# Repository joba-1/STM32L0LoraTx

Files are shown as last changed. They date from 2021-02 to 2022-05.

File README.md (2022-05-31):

# STM32L0LoraTx

Firmware and PCB for a device that sends data with a STM32L0/RFM95, battery or solar powered, to a [LoraGW ESP8266/RFM95 node](https://github.com/joba-1/LoraGw)

## Build

* Download and install STM32CubeIDE (as of now version 1.5.1)
* Import this repo
* Open .ioc file and select "Project/Generate Code" (should download needed "firmware" files for the chip from ST)
* Build Release or Debug

## Wiring

connect Gnd of all components

### STM32L011

Not checked without, but generally recommended to use a small ceramic (~10nF) and big electrolyt condensator (~10µF) between + and - near STM pins

* Look at the ioc file with CubeMX pinout view.
* Vdd _and_ Vdda to 1.8-3.3V
* Vss to Gnd
* Boot0 pulled to Gnd (~10k) to safely boot from flash
* STLink for flashing and debug: SWD, SWC, Gnd, NRst (also can provide Vdd via JP1 and STLink-Rx to L0-Tx for serial out)

### BME280

* SDA=MOSI, SDC=MISO, others should be obvious

### RFM95W

* Ant=~8cm wire (vary length and position to get best average RSSI as reported by LoraRx). 
* NSS=CS, others should be obvious

### Serial

Rx of a usb to serial converter sends at 115200. I use this command (serial port name ttyUSB_ser_red is defined in my /etc/udev/rules.d)
    pio device monitor -p /dev/ttyUSB_ser_red -b 115200

### LED

can be used without resistor. I use 1kOhm to save battery

## References

Good resource for STM32 is [Stefan Frings](http://stefanfrings.de/stm32/stm32l0.html)
He has links to reference, datasheet, errata and more. E.g.:

* [STM32L011 Datasheet](https://www.st.com/resource/en/datasheet/stm32l011d3.pdf)
* [STM32L011 Reference](https://www.st.com/resource/en/reference_manual/dm00108282-ultra-low-power-stm32l0x1-advanced-arm-based-32-bit-mcus-stmicroelectronics.pdf)
* [STM32L011 Errata](https://www.st.com/resource/en/errata_sheet/dm00237371-stm32l011x3-4-device-limitations-stmicroelectronics.pdf)
* [Power consumption](http://www.st.com/content/ccc/resource/technical/document/application_note/27/58/8e/81/79/fb/4f/ac/DM00108286.pdf/files/DM00108286.pdf/jcr:content/translations/en.DM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)

## Power Info Bits

* Examples for LL are here: STM32Cube/Repository/STM32Cube_FW_L0_V1.11.2/Projects/NUCLEO-L073RZ/Examples_LL/RTC/RTC_ExitStandbyWithWakeUpTimer
* Periodic wakeup timer is in Reference 22.4.6 (Periodic auto-wakeup)
* 1s to 18h periodic wakeup with ck_spre = 1s (see 22.4.3) and WUCKSEL [2:1] = 10
* Enable by WUTE bit in RTC_CR register
* Once setup it runs in normal and low power. 
* Sets WUTF flag in RTC_ISR if elapsed and reloads RTC_WUTR (timer counter). User resets WUTF
* Set WUTIE bit in RTC_CR to generate interrupt to wake up from low power modes
* System reset and Sleep, Stop, Standby have no influence on the WUT (wakeup timer)
* Save Lora frame counter in backup register: Reference 22.7.20 RTC backup registers (RTC_BKPxR)
* I couldnt make it work with LL lib, had to use big fat HAL for RCC and RTC. What is missing?

        LL_RTC_DisableWriteProtection(RTC);
        LL_RTC_WAKEUP_Disable(RTC);
        while( !LL_RTC_IsActiveFlag_WUTW(RTC) );
        LL_RTC_WAKEUP_SetClock(RTC, LL_RTC_WAKEUPCLOCK_CKSPRE);
        LL_RTC_WAKEUP_SetAutoReload(RTC, 3); // wake up every 3+1 s
        LL_RTC_EnableIT_WUT(RTC);
        LL_RTC_WAKEUP_Enable(RTC);
        LL_RTC_EnableWriteProtection(RTC);
        while( LL_RTC_IsActiveFlag_WUTW(RTC) );
        LL_RTC_ClearFlag_WUT(RTC);
        NVIC_ClearPendingIRQ(RTC_IRQn);

## Status

Working and sending LoRa packets to my LoraGW ESP8266 gateway (battery voltages and bme280 weather data)

Two devices operating with 2 AA 1.5V batteries (so far using 0.2-0.4 V per year, so >5 years between battery swaps is more than realistic).
They send battery voltage data from within a car trunc - not ideal for RF :) - to a nearby house with no signal problems.

One device runs "forever" with a 3.7 Lipo ~1.6Ah, a ~3x8 cm² 5V solar cell and a small solar charger board (reducing vcc out a bit with a diode). No capacity problems during winter.

## Todo

* Provide more sensor data (probably more ADC stuff and more generic)
* Move GPIO pins (CS, LED) to non-ADC pins to have them available for voltage measurements

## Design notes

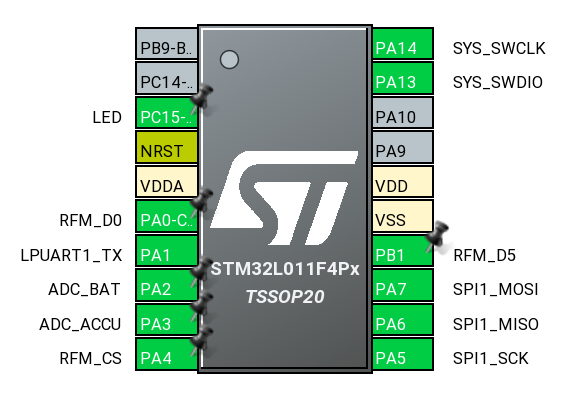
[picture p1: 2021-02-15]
STM32L011-TSSOP20-pinout.png

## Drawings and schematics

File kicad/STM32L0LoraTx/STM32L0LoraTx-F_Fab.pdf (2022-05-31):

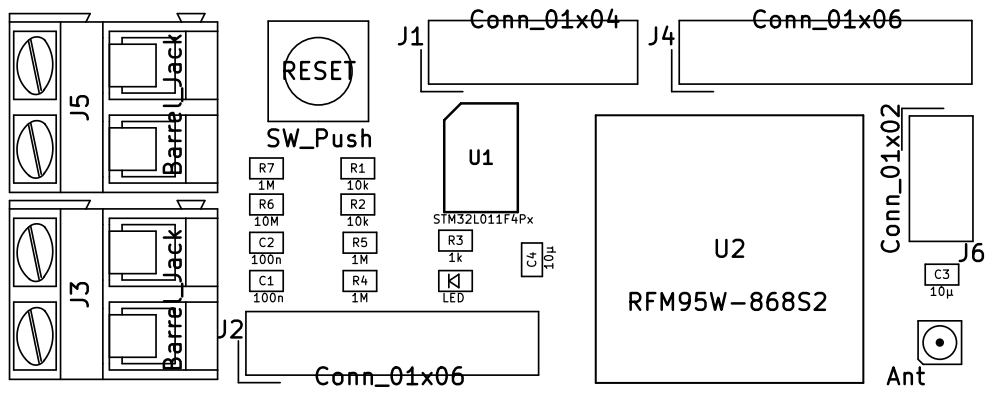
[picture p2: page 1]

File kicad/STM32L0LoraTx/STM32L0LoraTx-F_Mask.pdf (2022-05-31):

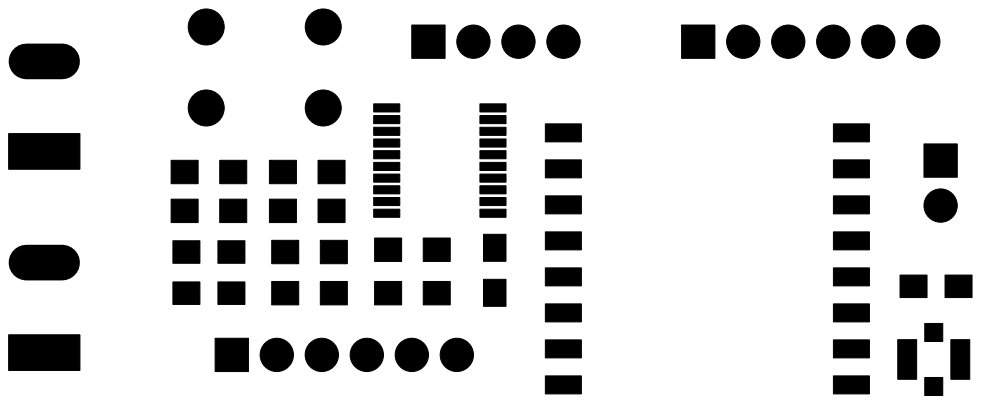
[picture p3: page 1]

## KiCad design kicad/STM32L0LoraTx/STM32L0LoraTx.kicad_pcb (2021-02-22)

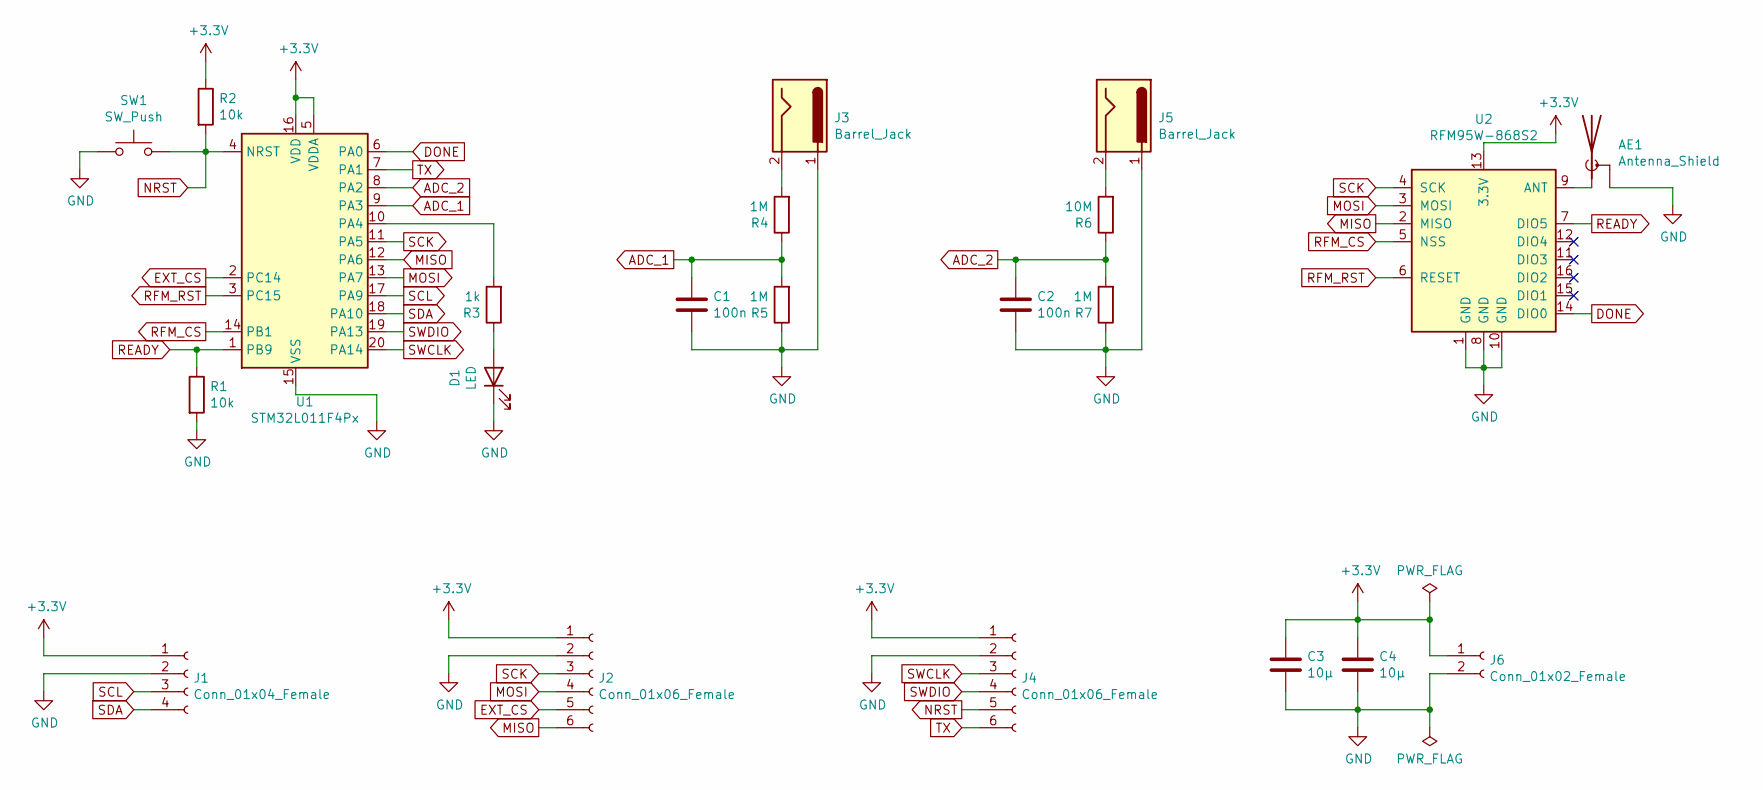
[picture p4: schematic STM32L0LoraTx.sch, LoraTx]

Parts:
AE1: Antenna_Shield; Molex_Microcoaxial_RF
C1, C2: 100n; C_0805_HandSoldering
C3, C4: 10µ; C_0805_HandSoldering
D1: LED; LED_0805_HandSoldering
J1: Conn_01x04_Female; JST_EH_B04B-EH-A_04x2.50mm_Straight
J2, J4: Conn_01x06_Female; JST_EH_B06B-EH-A_06x2.50mm_Straight
J3, J5: Barrel_Jack; TerminalBlock_Altech_AK300-2_P5.00mm
J6: Conn_01x02_Female; JST_EH_B02B-EH-A_02x2.50mm_Straight
R1, R2: 10k; R_0805_HandSoldering
R3: 1k; R_0805_HandSoldering
R4, R5, R7: 1M; R_0805_HandSoldering
R6: 10M; R_0805_HandSoldering
SW1: SW_Push; SW_PUSH_6mm_h5mm
U1: STM32L011F4Px; TSSOP-20_4.4x6.5mm_Pitch0.65mm
U2: RFM95W-868S2; Hopref_RFM9XW_SMD

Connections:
+3V3: C3.1, C4.1, J1.1, J2.1, J4.1, J6.1, R2.1, U1.5 (VDDA), U1.16 (VDD), U2.13 (3.3V)
ADC_1: C1.1, R4.1, R5.2, U1.9 (PA3)
ADC_2: C2.1, R6.1, R7.2, U1.8 (PA2)
DONE: U1.6 (PA0), U2.14 (DIO0)
EXT_CS: J2.5, U1.2 (PC14)
GND: AE1.2 (Shield), C1.2, C2.2, C3.2, C4.2, D1.1 (K), J1.2, J2.2, J3.1, J4.2, J5.1, J6.2, R1.2, R5.1, R7.1, SW1.1, U1.15 (VSS), U2.1 (GND), U2.8 (GND), U2.10 (GND); also elsewhere on the board
MISO: J2.6, U1.12 (PA6), U2.2 (MISO)
MOSI: J2.4, U1.13 (PA7), U2.3 (MOSI)
NRST: J4.5, R2.2, SW1.2, U1.4 (NRST); also elsewhere on the board
unnamed: AE1.1 (A), U2.9 (ANT)
unnamed: D1.2 (A), R3.1
unnamed: J3.2, R4.2
unnamed: J5.2, R6.2
unnamed: R3.2, U1.10 (PA4)
READY: R1.1, U1.1 (PB9), U2.7 (DIO5)
RFM_CS: U1.14 (PB1), U2.5 (NSS)
RFM_RST: U1.3 (PC15), U2.6 (RESET)
SCK: J2.3, U1.11 (PA5), U2.4 (SCK)
SCL: J1.3, U1.17 (PA9)
SDA: J1.4, U1.18 (PA10)
SWCLK: J4.3, U1.20 (PA14)
SWDIO: J4.4, U1.19 (PA13)
TX: J4.6, U1.7 (PA1)

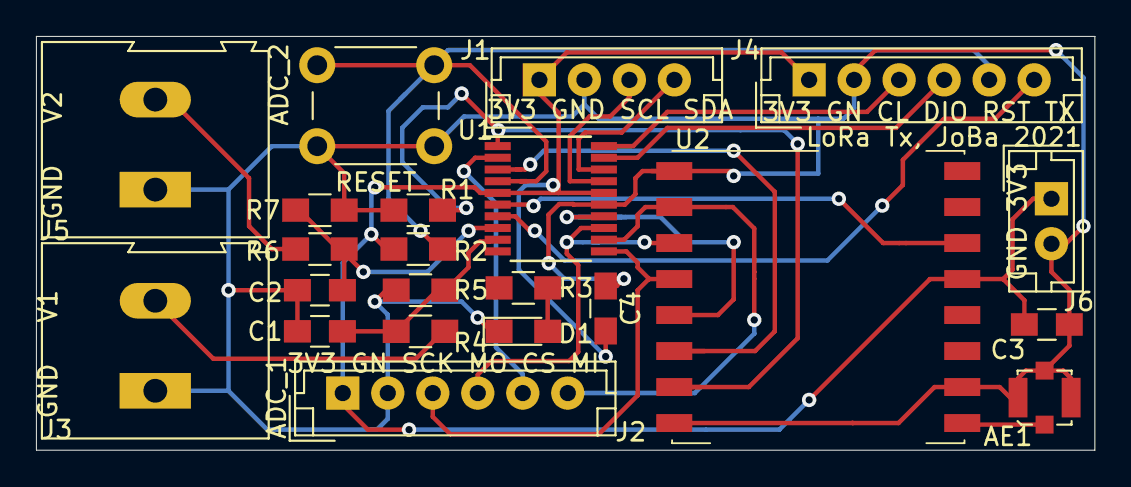
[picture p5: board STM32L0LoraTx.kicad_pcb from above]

Board: 2 copper layers, 58.8 x 23.0 mm, 22 parts (0 on the bottom side), 23 nets.

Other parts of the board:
RESET: SW_Push; SW_PUSH_6mm_h5mm

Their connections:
GND: RESET.1; also elsewhere on the board
NRST: RESET.2; also elsewhere on the board

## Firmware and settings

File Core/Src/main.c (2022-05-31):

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
/* Includes ------------------------------------------------------------------*/
#include "main.h"
#include "adc.h"
#include "usart.h"
#include "rtc.h"
#include "spi.h"
#include "gpio.h"

/* USER CODE BEGIN Includes */

#include <bme280.h>
#include <rfm95.h>
#include <payload.h>
///#include <lorawan.h>
///#include <secconfig.h>

/* USER CODE END Includes */

/* USER CODE BEGIN PTD */

typedef struct pins {
  GPIO_TypeDef *port;
  uint32_t pin;
} pin_t;

/* USER CODE END PTD */

/* USER CODE BEGIN PD */

// no LED and no UART after this frame
#define QUIET_FRAME 10

/* USER CODE END PD */


/* USER CODE BEGIN PV */

// BME280 driver requires SPI read/write interface functions to use only one uint8 as device id.
// STM32 pins in LL libs are defined by port and pin so pin alone cannot be used as device id.
// To be able to reuse the same SPI functions for RFM and BME280, I use a dev -> port/pin mapping table
pin_t pins[] = { { BME_CS_GPIO_Port, BME_CS_Pin }, { RFM_CS_GPIO_Port,
RFM_CS_Pin }, { RFM_D0_GPIO_Port, RFM_D0_Pin }, { RFM_D5_GPIO_Port,
RFM_D5_Pin } };

// must correspond to array index above
typedef enum {
  BME280_CS_PIN_ID, RFM95_NSS_PIN_ID, RFM95_DIO0_PIN_ID, RFM95_DIO5_PIN_ID
} pin_id_t;

struct bme280_dev bme280_dev;
struct bme280_data bme280_data;
uint32_t bme280_delay;

rfm95_t rfm95_dev;
uint8_t rfm95_ver;
///lorawan_t lorawan;
uint16_t frame_counter;
payload_t payload = { 0 };

/* USER CODE END PV */

void SystemClock_Config(void);
/* USER CODE BEGIN 0 */

void putstr(const char *str) {
  if (frame_counter > QUIET_FRAME)
    return;
  LL_LPUART_Enable(LPUART1);
  while (*str) {
    while (!LL_LPUART_IsActiveFlag_TXE(LPUART1))
      ;
    LL_LPUART_TransmitData8(LPUART1, (uint8_t) *str++);
  }
  while (!LL_LPUART_IsActiveFlag_TC(LPUART1))
    ;
  LL_LPUART_Disable(LPUART1);

//  if (frame_counter > QUIET_FRAME)
//    return;
//  LL_USART_Enable(USART2);
//  while (*str) {
//    while (!LL_USART_IsActiveFlag_TXE(USART2))
//      ;
//    LL_USART_TransmitData8(USART2, (uint8_t) *str++);
//  }
//  while (!LL_USART_IsActiveFlag_TC(USART2))
//    ;
//  LL_USART_Disable(USART2);
}

void putul(unsigned long u) {
  if (frame_counter > QUIET_FRAME)
    return;
  char num[11];
  char *d = &num[sizeof(num) - 1];
  *d = '\0';
  if (u) {
    while (u) {
      *(--d) = '0' + u % 10;
      u /= 10;
    }
  } else {
    *(--d) = '0';
  }
  putstr(d);
}

void putl(long u) {
  if (u < 0) {
    putstr("-");
    u = -u;
  }
  putul(u);
}

void puthex(uint8_t val) {
  if (frame_counter > QUIET_FRAME)
    return;
  static char hex[] = "0123456789abcdef";
  char msg[3];
  msg[0] = hex[val >> 4];
  msg[1] = hex[val & 0xf];
  msg[2] = '\0';
  putstr(msg);
}

void putlhex(uint32_t val) {
  puthex((val >> 24) & 0xff);
  puthex((val >> 16) & 0xff);
  puthex((val >> 8) & 0xff);
  puthex(val & 0xff);
}

int8_t duplexSpi(uint8_t dev, uint8_t addr, uint8_t *data, uint16_t len) {
  LL_SPI_Enable(SPI1);
  LL_GPIO_ResetOutputPin(pins[dev].port, pins[dev].pin);

  LL_SPI_TransmitData8(SPI1, addr);

  while (!LL_SPI_IsActiveFlag_RXNE(SPI1))
    ;   // wait for rx to finish
  LL_SPI_ReceiveData8(SPI1);                 // avoid overflow

  while (len--) {
    while (!LL_SPI_IsActiveFlag_TXE(SPI1))
      ;  // wait for tx to finish
    LL_SPI_TransmitData8(SPI1, *data);  // send data or generate clock for slave

    while (!LL_SPI_IsActiveFlag_RXNE(SPI1))
      ; // wait for rx to finish
    *data = LL_SPI_ReceiveData8(SPI1);       // read receive result
    data++;
  }

  while (LL_SPI_IsActiveFlag_BSY(SPI1))
    ;
  LL_GPIO_SetOutputPin(pins[dev].port, pins[dev].pin);
  LL_SPI_Disable(SPI1);

  return 0;
}

uint8_t readPin(uint8_t dev) {
  return LL_GPIO_IsInputPinSet(pins[dev].port, pins[dev].pin);
}

uint8_t* serialize(uint8_t *data, uint32_t value, size_t size) {
  while (size--) {
    *(data++) = value & 0xff;
    value >>= 8;
  }
  return data;
}

// use my measured values at ambient temperature for calibration if CAL1 is not available (STM32L011)
#ifndef TEMPSENSOR_CAL1_TEMP
#define TEMPSENSOR_CAL1_TEMP 20
#endif
#ifndef TEMPSENSOR_CAL1_ADDR
#define TEMPSENSOR_CAL1_RAW 1022
#else
#define TEMPSENSOR_CAL1_RAW (*TEMPSENSOR_CAL1_ADDR)
#endif

int32_t deci_celsius(uint32_t raw) {
  int32_t dc = (int32_t) raw - TEMPSENSOR_CAL1_RAW;
  dc *= (int32_t) TEMPSENSOR_CAL2_TEMP - TEMPSENSOR_CAL1_TEMP;
  dc *= 10;
  dc /= (int32_t) *TEMPSENSOR_CAL2_ADDR - TEMPSENSOR_CAL1_RAW;
  dc += (int32_t) TEMPSENSOR_CAL1_TEMP * 10;
  return dc;
}

uint32_t doConv() {
  LL_ADC_REG_StartConversion(ADC1);
  while (!LL_ADC_IsActiveFlag_EOC(ADC1))
    ;
  return (int32_t) LL_ADC_REG_ReadConversionData12(ADC1);
}

uint32_t getAdc(int32_t *mvbat, int32_t *mvaccu, int32_t *mvcc,
    int32_t *dcelsius) {
  LL_ADC_SetCommonPathInternalCh(ADC1_COMMON,
  LL_ADC_PATH_INTERNAL_VREFINT | LL_ADC_PATH_INTERNAL_TEMPSENSOR);
  LL_ADC_Enable(ADC1);
  while (!LL_ADC_IsActiveFlag_ADRDY(ADC1))
    ;

  LL_mDelay(10); // test: let ADC settle

  // Channel scan direction backwards
  uint32_t rawTemp = doConv();
  *mvcc = doConv();
  *mvbat = doConv();
  *mvaccu = doConv();
  uint32_t adc1_ch1 = doConv(); // adc1 ch2 pin defect on my chip. Reuse ch1 pin (lpuart tx)

  *mvcc = VREFINT_CAL_VREF * (*VREFINT_CAL_ADDR) / *mvcc; // calibrated voltage at vcc
  *mvbat = *mvcc * *mvbat / 4095; // compensate adc for varying vcc
  *mvaccu = *mvcc * *mvaccu / 4095; // compensate adc for varying vcc
  adc1_ch1 = *mvcc * adc1_ch1 / 4095; // compensate adc for varying vcc

  *mvaccu = adc1_ch1; // use ch1 data over defect ch2 data

  // calibrate voltage divider
  *mvbat -= 47; // fix compensated adc reading at 0V to 0
  *mvbat *= 5040; // actual voltage used for linear calibration
  *mvbat /= 2471 - 47; // actual compensated adc reading at calibration voltage

  // calibrate voltage divider
  *mvaccu -= 47; // fix compensated adc reading at 0V to 0
  *mvaccu *= 13000; // actual voltage used for linear calibration
  *mvaccu /= 1192 - 47; // actual compensated adc reading at calibration voltage

  *dcelsius = deci_celsius(rawTemp);
  //*dcelsius = adc1_ch1;

  while (!LL_ADC_IsActiveFlag_EOS(ADC1))
    ;
  LL_ADC_Disable(ADC1);

  return rawTemp;
}

void rfm_setup(uint32_t seed) {
  rfm95_dev.nss_pin_id = RFM95_NSS_PIN_ID;
  rfm95_dev.dio0_pin_id = RFM95_DIO0_PIN_ID;
  rfm95_dev.dio5_pin_id = RFM95_DIO5_PIN_ID;
  rfm95_dev.spi_write = duplexSpi;
  rfm95_dev.spi_read = duplexSpi;
  rfm95_dev.delay = LL_mDelay;
  rfm95_dev.pin_read = readPin;

  //while( rfm95_ver != 0x12 ) {
  rfm95_ver = rfm95_init(&rfm95_dev, seed);
  //}

  ///lorawan_init(&lorawan, &rfm95_dev);
  ///lorawan_set_keys(&lorawan, NwkSkey, AppSkey, DevAddr);

  // Print test package
  // if (0) {
  //   uint8_t buf[8];
  //   for (size_t i = 0; i < sizeof(buf); i++) {
  //     buf[i] = i;
  //   }
  //
  //   ///lorawan_send_data(&lorawan, buf, sizeof(buf), 0);
  //   unsigned char RFM_Data[] = "hello test world!";
  //   unsigned char RFM_Package_Length = sizeof(RFM_Data);
  //   rfm95_send(&rfm95_dev, RFM_Data, RFM_Package_Length);
  // }
}

int bme_setup() {
  bme280_dev.dev_id = BME280_CS_PIN_ID;
  bme280_dev.intf = BME280_SPI_INTF;
  bme280_dev.read = duplexSpi;
  bme280_dev.write = duplexSpi;
  bme280_dev.delay_ms = LL_mDelay;

  int bme_init = 0;
  int count = 5;

  while (!bme_init && count--) {
    if (bme280_init(&bme280_dev) == BME280_OK) {
      bme280_dev.settings.osr_h = BME280_OVERSAMPLING_1X;
      bme280_dev.settings.osr_p = BME280_OVERSAMPLING_16X;
      bme280_dev.settings.osr_t = BME280_OVERSAMPLING_2X;
      bme280_dev.settings.filter = BME280_FILTER_COEFF_16;
      if (bme280_set_sensor_settings(
          BME280_OSR_PRESS_SEL | BME280_OSR_TEMP_SEL | BME280_OSR_HUM_SEL
              | BME280_FILTER_SEL, &bme280_dev) == BME280_OK) {
        bme280_delay = bme280_cal_meas_delay(&bme280_dev.settings);
        putstr(" BME delayMs:");
        putul(bme280_delay);
        if (bme280_delay) {
          bme_init = 1;
        }
      } else {
        putstr(" BME setup error!\n");
      }
    } else {
      putstr(" BME init error!\n");
    }

    if (!bme_init) {
      if (!count) {
        return 0;
      }
      LL_mDelay(100);
    }
  }

  return 1;
}

int bme_read() {
  bme280_data.humidity = 0;
  if (bme280_set_sensor_mode(BME280_FORCED_MODE, &bme280_dev) == BME280_OK) {
    bme280_dev.delay_ms(bme280_delay);
    bme280_get_sensor_data(BME280_ALL, &bme280_data, &bme280_dev);
  }

  return bme280_data.humidity > 0 && bme280_data.humidity <= 100000
      && bme280_data.pressure > 81000 && bme280_data.pressure < 110000
      && bme280_data.temperature > -50000 && bme280_data.temperature <= 9500;
}

void bme_print() {
  putstr(" T:");
  putul(bme280_data.temperature);
  putstr(" c°C, H:");
  putul(bme280_data.humidity);
  putstr(" m%, P:");
  putul(bme280_data.pressure);
  putstr(" Pa");
}

void lora_tx() {
  putstr(" standbys:");
  putul(frame_counter);

  int32_t mvbat = 0, mvaccu = 0, mvcc = 0, dcelsius = 0;

  uint32_t raw_temp = getAdc(&mvbat, &mvaccu, &mvcc, &dcelsius);

  payload.data.mVcc = mvcc;
  payload.data.mVbat = mvbat;

  putstr(" mVcc:");
  putl(payload.data.mVcc);
  putstr(" mVbat:");
  putl(payload.data.mVbat);

#ifdef PAYLOAD_BME
  bme_read();

  payload.data.mpHumi = bme280_data.humidity;
  payload.data.paPressure = bme280_data.pressure;
  payload.data.ctCelsius = (int16_t) bme280_data.temperature;

  putstr(" mpHumi:");
  putl(payload.data.mpHumi);
  putstr(" paPressure:");
  putl(payload.data.paPressure);
  putstr(" ctCelsius:");
  putl(payload.data.ctCelsius);
#else
  payload.data.mVbat = mvbat;
  payload.data.mVaccu = mvaccu;
  payload.data.dCelsius = (int16_t) dcelsius;

  putstr(" mVbat:");
  putl(payload.data.mVbat);
  putstr(" mVaccu:");
  putl(payload.data.mVaccu);
  putstr(" dCelsius:");
  putl(payload.data.dCelsius);
#endif

  putstr(" rawTemp:");
  putul(raw_temp);

  putstr(" send ");
  payload_make_valid(&payload);
  putul(rfm95_send(&rfm95_dev, (uint8_t*) &payload, sizeof(payload)) / 1000);
  ///putul(lorawan_send_data(&lorawan, Data, sizeof(Data), frame_counter)/1000);
  putstr(" kHz");

  LL_GPIO_ResetOutputPin(LED_GPIO_Port, LED_Pin);

  if (frame_counter == QUIET_FRAME) {
    putstr(" continue quietly\n");
  }

  if (frame_counter >= QUIET_FRAME) {
    HAL_RTCEx_SetWakeUpTimer_IT(&hrtc, INTERVAL_S * 5,
    RTC_WAKEUPCLOCK_CK_SPRE_16BITS);
  }

  HAL_RTCEx_BKUPWrite(&hrtc, RTC_BKP_DR0, ++frame_counter);

  // INTERVAL_S defined in *.ioc, Pinout & Configuration, RTC, Configuration
  putstr(" wake:");
  putul(INTERVAL_S);
  putstr(" s");

  HAL_PWREx_EnableUltraLowPower();
  HAL_PWREx_EnableFastWakeUp();
  __HAL_PWR_CLEAR_FLAG(PWR_FLAG_WU);
  HAL_PWR_EnterSTANDBYMode();

  // following should never be reached...
  putstr(" STANDBY ERROR\n");

  LL_mDelay(60000);

  HAL_DeInit();
  NVIC_SystemReset();
}

void lora_rx() {
  uint8_t buf[0xff];
  signal_t sig;
  uint32_t received = rfm95_recv(&rfm95_dev, buf, sizeof(buf), &sig);
  if (received) {
    LL_GPIO_SetOutputPin(LED_GPIO_Port, LED_Pin);
    putstr("\ngot ");
    putul(received);
    putstr(" bytes at snr ");
    putul(sig.snr);
    putstr(" rssi ");
    putul(sig.rssi);
    putstr(": ");
    for (uint32_t pos = 0; pos < received; pos++) {
      puthex(buf[pos]);
    }
    LL_GPIO_ResetOutputPin(LED_GPIO_Port, LED_Pin);
  }
}

/* USER CODE END 0 */

/**
 * @brief  The application entry point.
 * @retval int
 */
int main(void) {
  /* MCU Configuration--------------------------------------------------------*/

  /* Reset of all peripherals, Initializes the Flash interface and the Systick. */
  HAL_Init();

  /* Configure the system clock */
  SystemClock_Config();

  /* Initialize all configured peripherals */
  MX_GPIO_Init();
  MX_RTC_Init();
  MX_SPI1_Init();
  MX_ADC_Init();
  MX_LPUART1_UART_Init();
  /* USER CODE BEGIN 2 */

  LL_GPIO_SetOutputPin(pins[BME280_CS_PIN_ID].port, pins[BME280_CS_PIN_ID].pin);
  LL_GPIO_SetOutputPin(pins[RFM95_NSS_PIN_ID].port, pins[RFM95_NSS_PIN_ID].pin);

  frame_counter = (uint16_t) HAL_RTCEx_BKUPRead(&hrtc, RTC_BKP_DR0);

  putstr("\nStart ST32ML0LoraTRx 1.6 " __DATE__ " " __TIME__ " device 0x");
  uint32_t *id_ptr = (uint32_t*) 0x1FF80050; // address of stm32L0 chip id (at offsets 0, 1 and 5)
  //putlhex(*id_ptr);
  //putlhex(*(id_ptr+1));
  putlhex(*(id_ptr + 5));
  payload.id = *(id_ptr + 5);

  if (__HAL_PWR_GET_FLAG(PWR_FLAG_SB) != RESET) {
    putstr(" from standby");
    __HAL_PWR_CLEAR_FLAG(PWR_FLAG_SB);
  } else {
    putstr(" from reset");
    frame_counter = 0;
    // At first power on give a button cell a bit of time
    // to charge a capacitor before sending something to prevent boot loop
    LL_GPIO_SetOutputPin(LED_GPIO_Port, LED_Pin);
    LL_mDelay(10);
    LL_GPIO_ResetOutputPin(LED_GPIO_Port, LED_Pin);
    LL_mDelay(1000);
  }

  // After a few standby cycles don't waste power on led
  if (frame_counter <= QUIET_FRAME) {
    LL_GPIO_SetOutputPin(LED_GPIO_Port, LED_Pin);
  }

#ifdef PAYLOAD_BME
  bme_setup();
#endif

  // Reset RFM chip - just to be sure...
  LL_GPIO_ResetOutputPin(RFM_NRST_GPIO_Port, RFM_NRST_Pin);
  LL_mDelay(1);
  LL_GPIO_SetOutputPin(RFM_NRST_GPIO_Port, RFM_NRST_Pin);
  LL_mDelay(5);

  rfm_setup(frame_counter);
  /* USER CODE END 2 */

  /* Infinite loop */
  /* USER CODE BEGIN WHILE */
  while (1) {
    lora_tx();
    // lora_rx();
    /* USER CODE END WHILE */

    /* USER CODE BEGIN 3 */
  }
  /* USER CODE END 3 */
}

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


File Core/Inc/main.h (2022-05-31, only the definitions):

#define INTERVAL_S 60
#define RFM_D5_Pin LL_GPIO_PIN_9
#define RFM_D5_GPIO_Port GPIOB
#define BME_CS_Pin LL_GPIO_PIN_14
#define BME_CS_GPIO_Port GPIOC
#define RFM_NRST_Pin LL_GPIO_PIN_15
#define RFM_NRST_GPIO_Port GPIOC
#define RFM_D0_Pin LL_GPIO_PIN_0
#define RFM_D0_GPIO_Port GPIOA
#define ADC_ACCU_Pin LL_GPIO_PIN_2
#define ADC_ACCU_GPIO_Port GPIOA
#define ADC_BAT_Pin LL_GPIO_PIN_3
#define ADC_BAT_GPIO_Port GPIOA
#define LED_Pin LL_GPIO_PIN_4
#define LED_GPIO_Port GPIOA
#define RFM_CS_Pin LL_GPIO_PIN_1
#define RFM_CS_GPIO_Port GPIOB

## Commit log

2021-02-03 Lora Rx Tx working
    [4x4-buttoncell-B.Cu.gbl, 4x4-buttoncell-B.Mask.gbs, 4x4-buttoncell-B.SilkS.gbo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]
2021-02-04 payload with temperature
2021-02-06 use temperature sensor
2021-02-06 ADC internal channel tests
2021-02-07 calibrated adc and allow neg voltage
2021-02-15 final voltage divider calibration
2021-02-15 add STM pin config
2021-02-22 add kicad
    [STM32L0LoraTx.kicad_pcb, STM32L0LoraTx.sch]
2022-05-31 pcb v4 board
    [STM32L0LoraTx-vl53l.kicad_pcb, STM32L0LoraTx.kicad_pcb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]
2022-05-31 add bme280 support
    [STM32L0LoraTx-black-labels.kicad_pcb]

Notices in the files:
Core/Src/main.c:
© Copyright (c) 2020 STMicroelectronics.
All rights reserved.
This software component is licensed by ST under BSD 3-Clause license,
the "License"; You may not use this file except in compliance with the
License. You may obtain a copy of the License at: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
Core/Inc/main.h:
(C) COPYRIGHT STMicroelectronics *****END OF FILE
